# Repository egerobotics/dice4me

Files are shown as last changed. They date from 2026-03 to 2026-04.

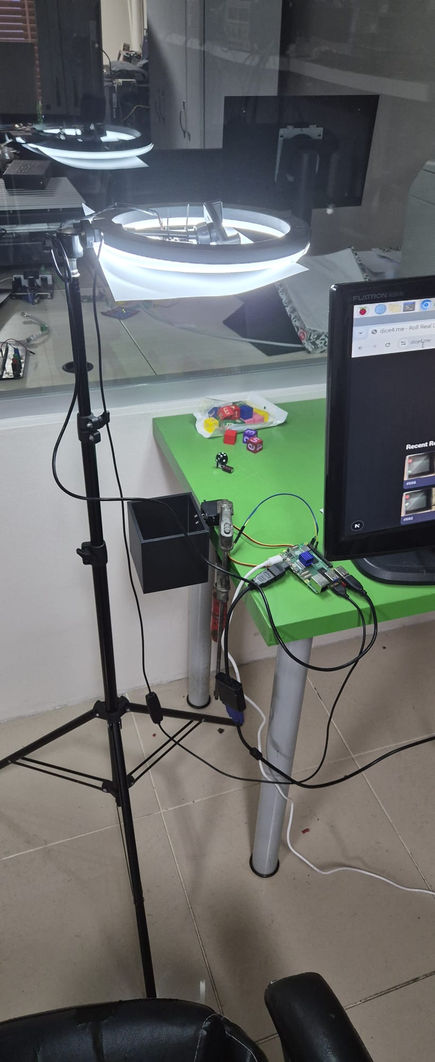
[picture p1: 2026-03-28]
HARDWARE/MECHANICS.jpeg

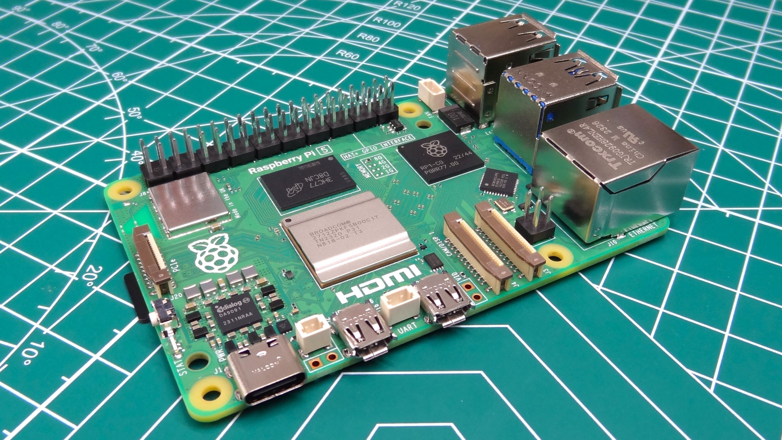
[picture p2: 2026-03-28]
HARDWARE/RASPBERRY_PI_5.jpg

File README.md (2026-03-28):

# dice4.me

Roll real physical dice remotely and see the result on camera.

A web application that controls a physical dice-rolling mechanism via a Raspberry Pi. Users can roll dice from the website or by mentioning [@dice4me](https://x.com/dice4me) on X.com.

## How It Works

```
User (Web/X.com) → VPS (Next.js) → Raspberry Pi → Servo rolls dice → Camera captures result → Photo displayed
```

1. User clicks "Roll Dice" on [dice4.me](https://dice4.me) or tweets `@dice4me roll`
2. VPS sends a trigger to the Raspberry Pi
3. Pi moves an RC servo to physically shake and roll two dice
4. Pi captures a photo from a USB camera
5. Photo is sent back to VPS, watermarked with roll number, and displayed
6. For X.com rolls: bot replies with the roll number and result photo

## Architecture

### VPS (dice4.me)
- **Next.js 15** (App Router) - Web frontend and API
- **PostgreSQL** + **Prisma** - Roll history and settings
- **Twitter API v2** - Filtered stream for real-time mention detection
- **Cloudflare Turnstile** - Bot protection
- **Sharp** - Photo watermarking (roll number, X.com username)

### Raspberry Pi 5
- **Fastify** - HTTP server for trigger and camera stream endpoints
- **gpiozero** (Python) - Servo motor control via GPIO
- **ffmpeg** - USB camera MJPEG stream and photo capture

## Project Structure

```
/home/dice4me/
├── app/
│   ├── page.tsx                    # Landing page
│   ├── components/                 # React components
│   └── api/
│       ├── roll/route.ts           # POST: trigger roll, GET: history
│       ├── roll/[id]/route.ts      # GET: poll roll status
│       ├── roll/callback/route.ts  # POST: Pi sends result here
│       ├── rolls/[filename]/       # GET: serve roll photos
│       └── stream/route.ts         # GET: proxy camera snapshot
├── lib/
│   ├── db.ts                       # Prisma client
│   ├── pi.ts                       # Pi trigger helper
│   ├── twitter.ts                  # Twitter API (reply, retweet, post)
│   └── twitter-stream.ts           # Filtered stream listener
├── prisma/schema.prisma            # Database schema
├── pi/                             # Raspberry Pi codebase
│   └── src/
│       ├── index.ts                # Fastify server
│       ├── servo.ts                # Servo control (gpiozero/lgpio)
│       ├── camera.ts               # Photo capture from stream
│       └── stream.ts               # MJPEG stream from USB camera
└── data/rolls/                     # Saved roll photos
```

## Hardware

- Raspberry Pi 5
- SG90 or MG996R servo motor (GPIO 18)
- USB webcam (1280x720)
- Dice tray attached to servo arm
- 2x standard 6-sided dice

## Setup

### VPS

```bash
npm install
npx prisma db push
npm run build
npm start
```

### Raspberry Pi

```bash
cd pi
npm install
sudo apt install ffmpeg
sudo tsx src/index.ts
```

### Environment Variables

See `.env.local` for required variables:
- `PI_TRIGGER_URL` - Pi trigger endpoint
- `DICE4ME_API_KEY` - Shared API key
- `TWITTER_*` - Twitter API credentials
- `TURNSTILE_*` - Cloudflare Turnstile keys
- `DATABASE_URL` - PostgreSQL connection string

## X.com Integration

- Mention `@dice4me roll` to trigger a dice roll
- Must be following @dice4me to use
- Bot replies with roll number, then result photo
- Result photo is retweeted to main timeline
- Web rolls are also posted as tweets

## Services

| Service | Description |
|---|---|
| `dice4me-web` | Next.js production server (VPS) |
| `dice4me-twitter` | Twitter filtered stream listener (VPS) |
| `dice4me-pi` | Pi server with servo + camera (Raspberry Pi) |

## License

[MIT](LICENSE)

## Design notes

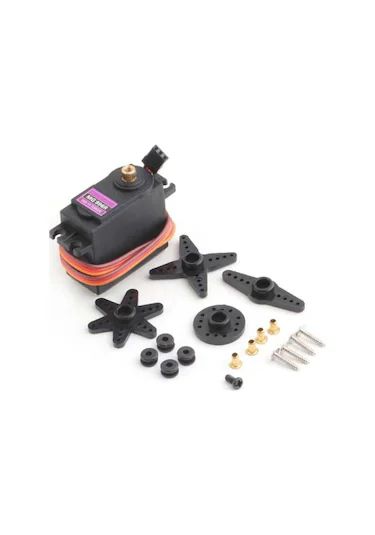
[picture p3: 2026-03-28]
HARDWARE/MG996.jpg

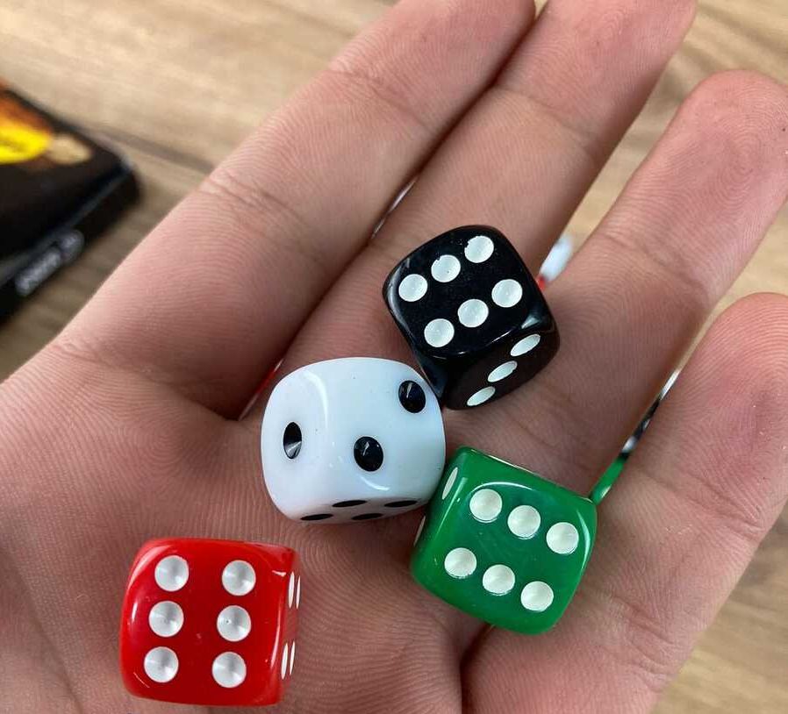
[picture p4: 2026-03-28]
HARDWARE/DICES.jpg

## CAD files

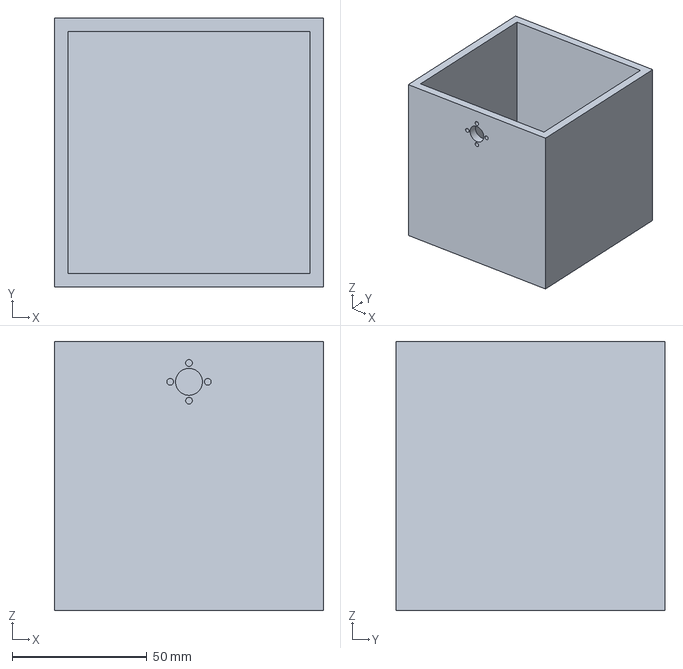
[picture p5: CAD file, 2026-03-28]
HARDWARE/DICE4ME_ROLL_BOX.FCStd
100.0 x 100.0 x 100.0 mm

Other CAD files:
HARDWARE/DICE4ME_ROLL_BOX.stl

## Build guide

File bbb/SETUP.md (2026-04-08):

# BeagleBone White Setup

## 1. Prerequisites (BeagleBone Debian)

```bash
# Update system
sudo apt update && sudo apt install -y python3-pip ffmpeg curl

# Install Adafruit_BBIO for PWM/GPIO
sudo pip3 install Adafruit_BBIO --break-system-packages

# Install Node.js 20 (ARM build)
curl -fsSL https://deb.nodesource.com/setup_20.x | sudo -E bash -
sudo apt install -y nodejs

# Install tsx globally
sudo npm install -g tsx
```

## 2. Copy Project

```bash
mkdir -p ~/dice4me
# From VPS:
scp -r root@89.167.127.16:/home/dice4me/bbb/* ~/dice4me/
cd ~/dice4me
npm install
```

## 3. Configure Environment

```bash
cat > .env << 'EOF'
DICE4ME_API_KEY=a7ee96f888ee32cab54cacfa00635a7bcc2e719f50bc69843afbb771a927ddec
PORT=3001
SERVO_PIN=P9_14
PHOTO_CAM=/dev/video0
STREAM_CAM=/dev/video0
EOF
```

## 4. Hardware Wiring

- Servo signal → **P9_14** (PWM)
- Servo VCC → **P9_7** (5V) or external 5V supply
- Servo GND → **P9_1** or **P9_2** (GND)
- USB webcam → USB host port

## 5. Test Servo

```bash
sudo python3 -c "
import Adafruit_BBIO.PWM as PWM
import time
PWM.start('P9_14', 7.5, 50)
time.sleep(2)
PWM.stop('P9_14')
PWM.cleanup()
"
```

## 6. Run

```bash
cd ~/dice4me
sudo tsx src/index.ts
```

## 7. Auto-start with systemd

```bash
sudo cp dice4me-bbb.service /etc/systemd/system/dice4me-pi.service
sudo systemctl daemon-reload
sudo systemctl enable dice4me-pi
sudo systemctl start dice4me-pi
sudo systemctl status dice4me-pi
```

## Notes

- BeagleBone White only has 256MB RAM. Node.js + tsx will use ~100MB. Camera streaming may be tight.
- Consider running ffmpeg at lower resolution (`640x480` instead of `1280x720`) for better performance.
- Adafruit_BBIO requires root for PWM access.

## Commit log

2026-03-28 dice4me - Physical dice rolling web app with X.com integration
    - Next.js 15 web frontend with Cloudflare Turnstile bot protection
    - Raspberry Pi 5 servo control + USB camera for physical dice rolling
    - Twitter filtered stream for real-time @dice4me roll mentions
    - Photo watermarking with roll number and X.com username
    - PostgreSQL database for roll history
    - Systemd services for VPS and Pi auto-start
2026-03-28 Add hardware files (3D model, photos, mechanics video)
    [DICE4ME_ROLL_BOX.FCStd, DICE4ME_ROLL_BOX.stl]
2026-04-08 Add BeagleBone Black port
    - Sysfs PWM control for servo (P9_14 -> pwmchip5/pwm0)
    - fswebcam for USB camera capture (lighter than ffmpeg for low-RAM devices)
    - On-demand snapshot mode (no persistent stream)
    - Compiled JS execution with --max-old-space-size=96 for 256MB RAM
    - Setup documentation for Debian on BeagleBone
